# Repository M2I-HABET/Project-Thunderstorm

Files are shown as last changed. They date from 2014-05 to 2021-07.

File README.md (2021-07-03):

Project Thunderstorm
==================

Project Thunderstorm aims to launch high altitude balloons into thunderstorms in order to collect data. Multiple balloons will be launched to take data points at different points in the thunderstorm and to use a mesh network to help deliver information throughout the thunderstorm.

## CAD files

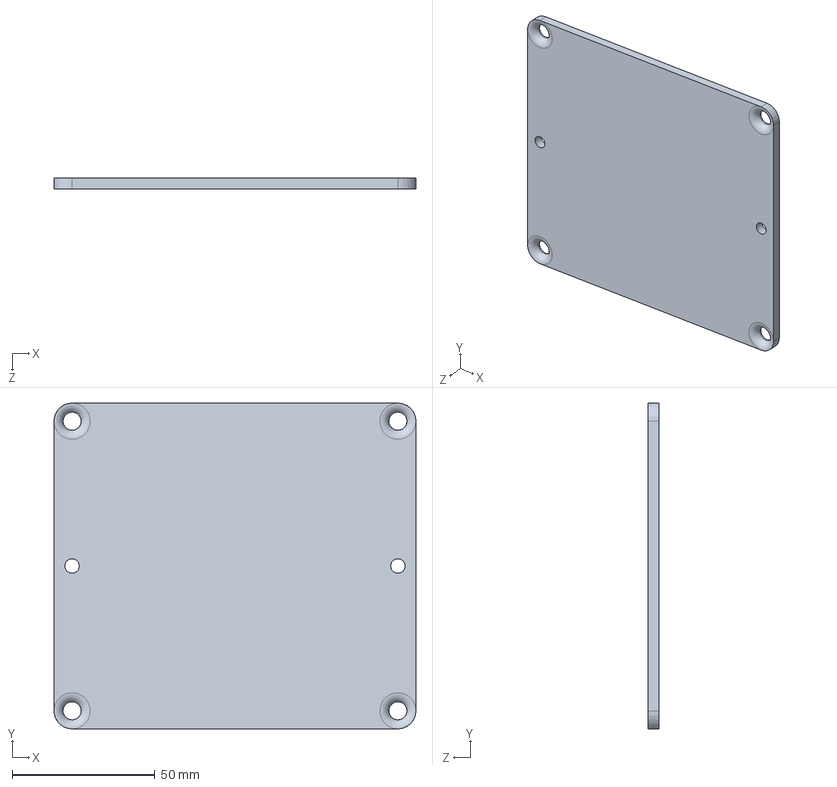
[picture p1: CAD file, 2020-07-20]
Enclosure/Lid 2.SLDPRT
127.0 x 114.3 x 3.81 mm

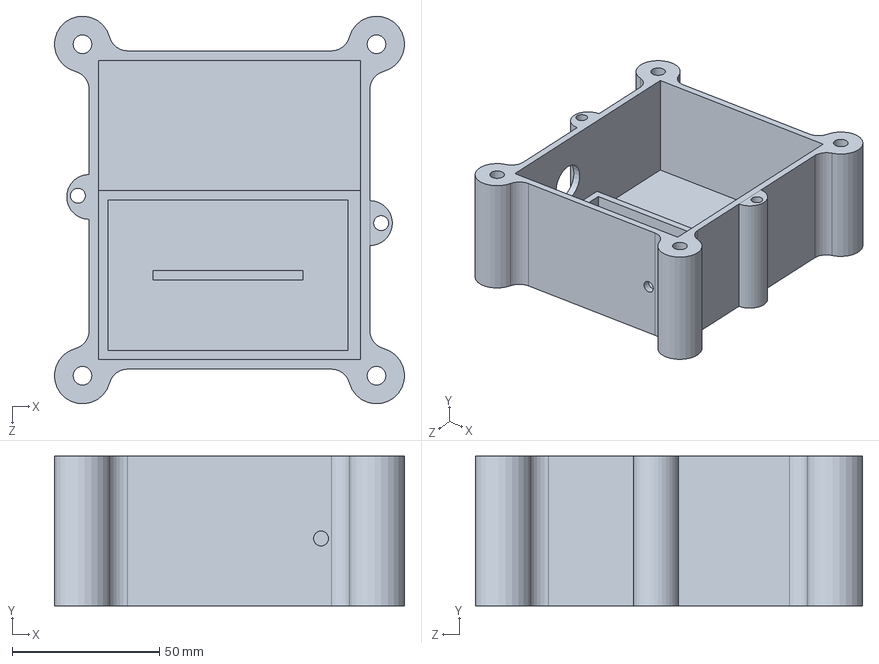
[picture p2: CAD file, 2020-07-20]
Enclosure/thunderstorm1.SLDPRT
118.7 x 50.8 x 131.4 mm

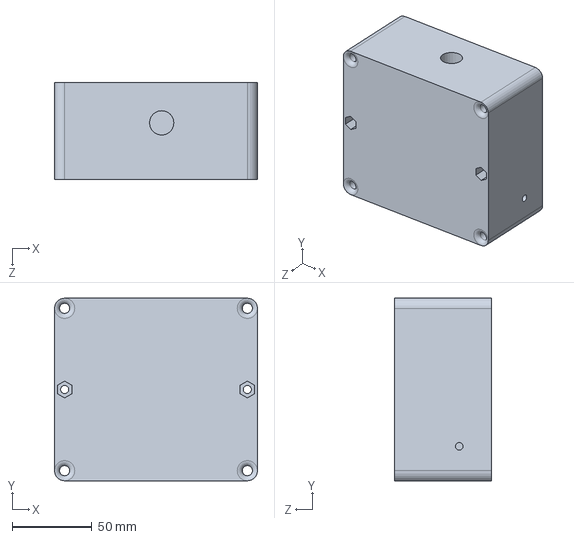
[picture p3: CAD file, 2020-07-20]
Enclosure/Box 2.SLDPRT
127.0 x 114.3 x 61.0 mm

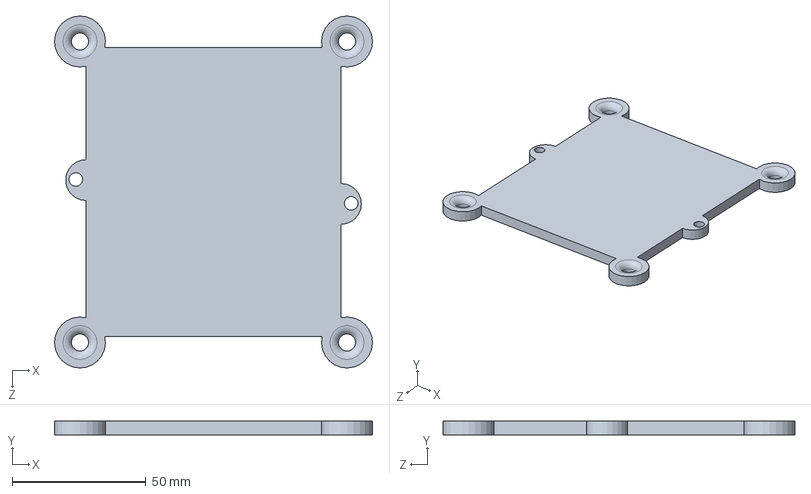
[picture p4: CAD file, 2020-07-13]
Enclosure/thunderstorm2.SLDPRT
118.8 x 5.08 x 131.5 mm

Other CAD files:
Enclosure/Box 2.STL
Enclosure/Lid 2.STL
Enclosure/thunderstorm1.STL
Enclosure/thunderstorm2.STL

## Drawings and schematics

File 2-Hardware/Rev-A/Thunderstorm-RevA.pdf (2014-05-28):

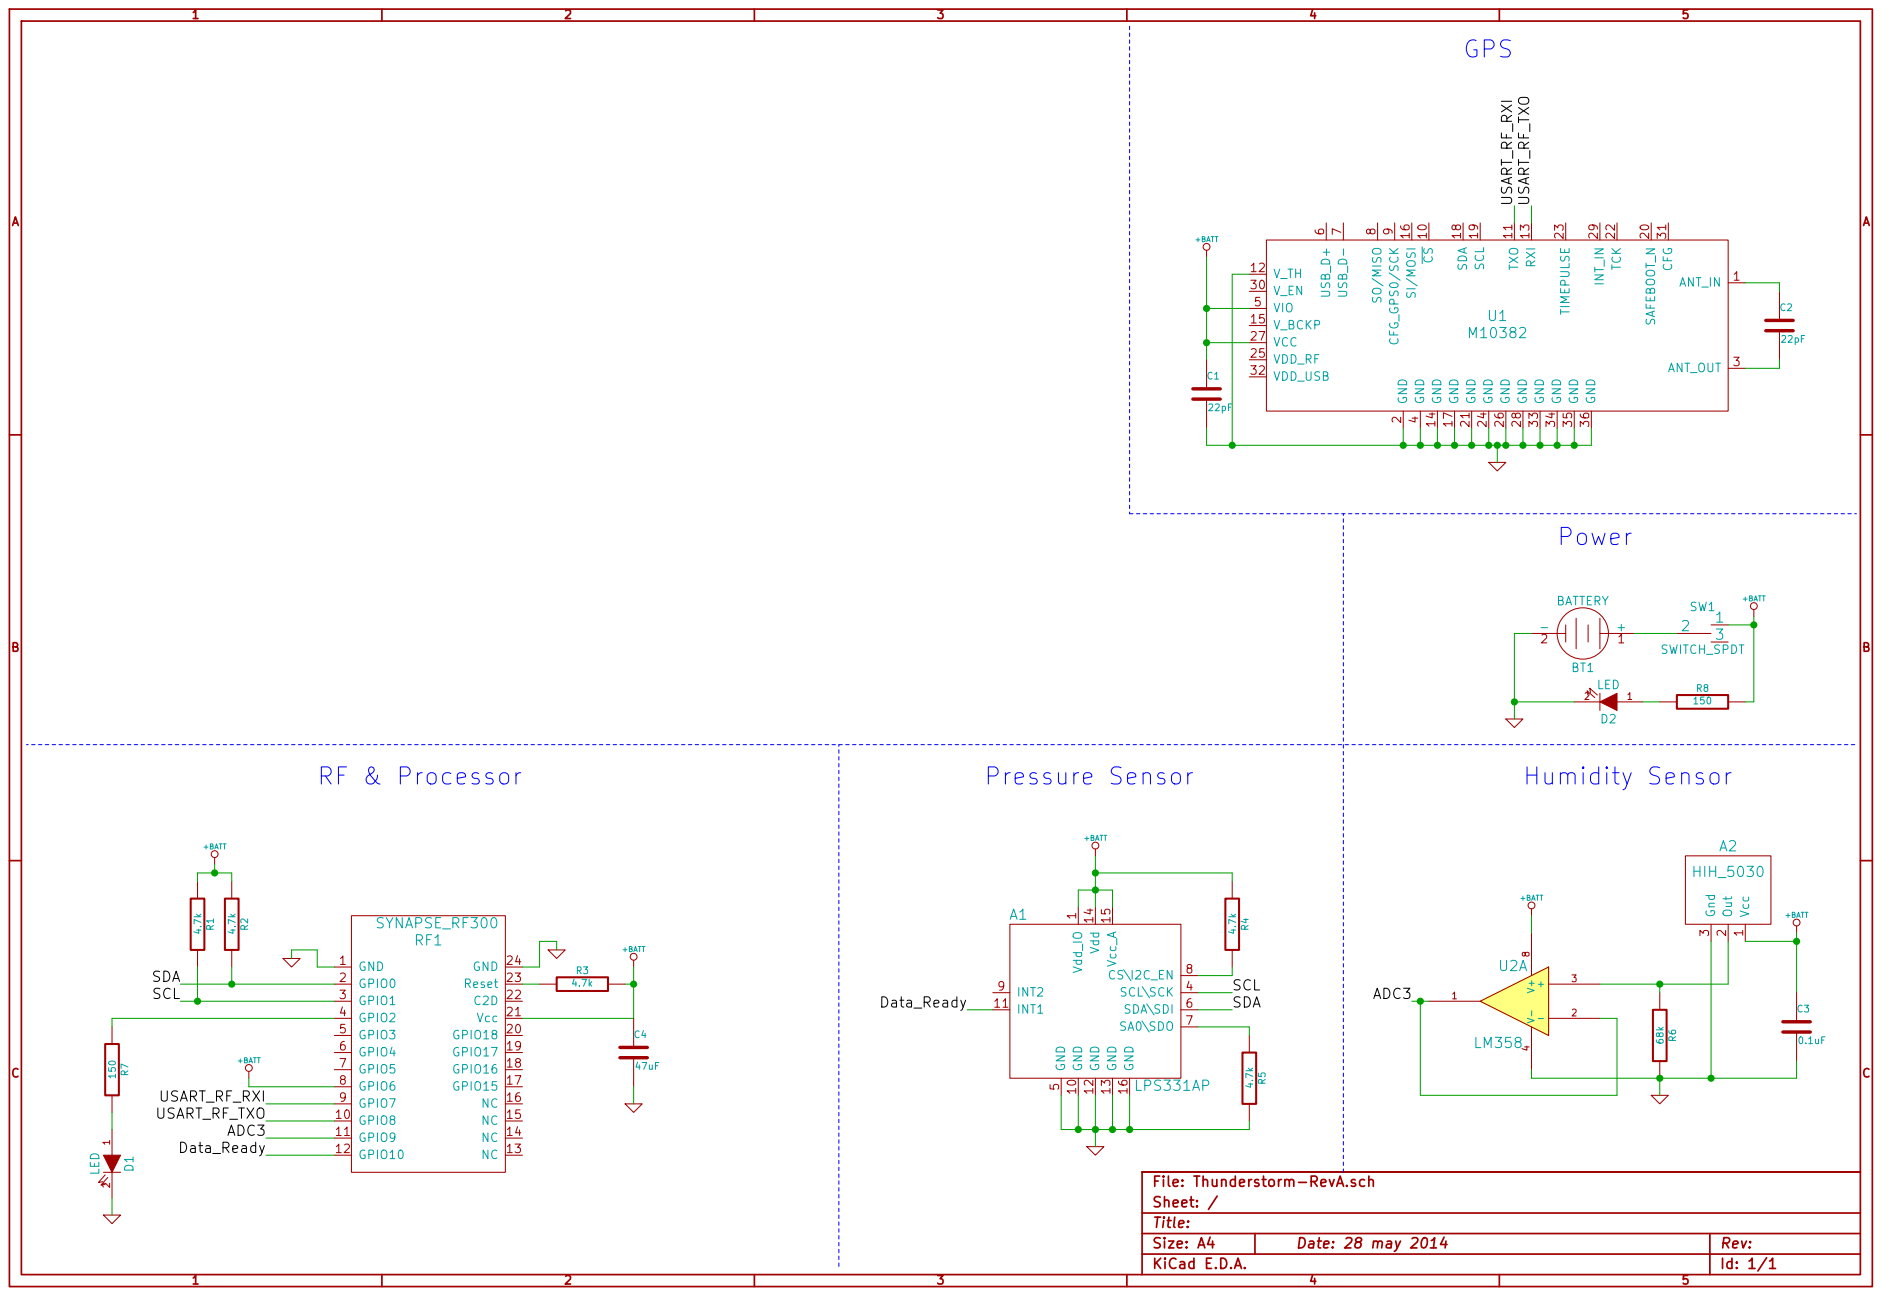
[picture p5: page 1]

9 CS 10 SAFEBOOT_N 20 V_EN 30 TXO 11 GND 21 CFG 31 V_TH 12 TCK 22 VDD_USB 32 RXI 13 TIMEPULSE 23 GND 33 GND 14 GND 24 GND 34 V_BCKP 15 VDD_RF 25 GND 35 SI/MOSI 16 GND 26 GND 36 GND 17 VCC 27 SDA 18 GND 28 SCL 19 INT_IN 29 U1 M10382
+BATT C1

5 SDA\SDI 6 SA0\SDO 7 CS\I2C_EN 8

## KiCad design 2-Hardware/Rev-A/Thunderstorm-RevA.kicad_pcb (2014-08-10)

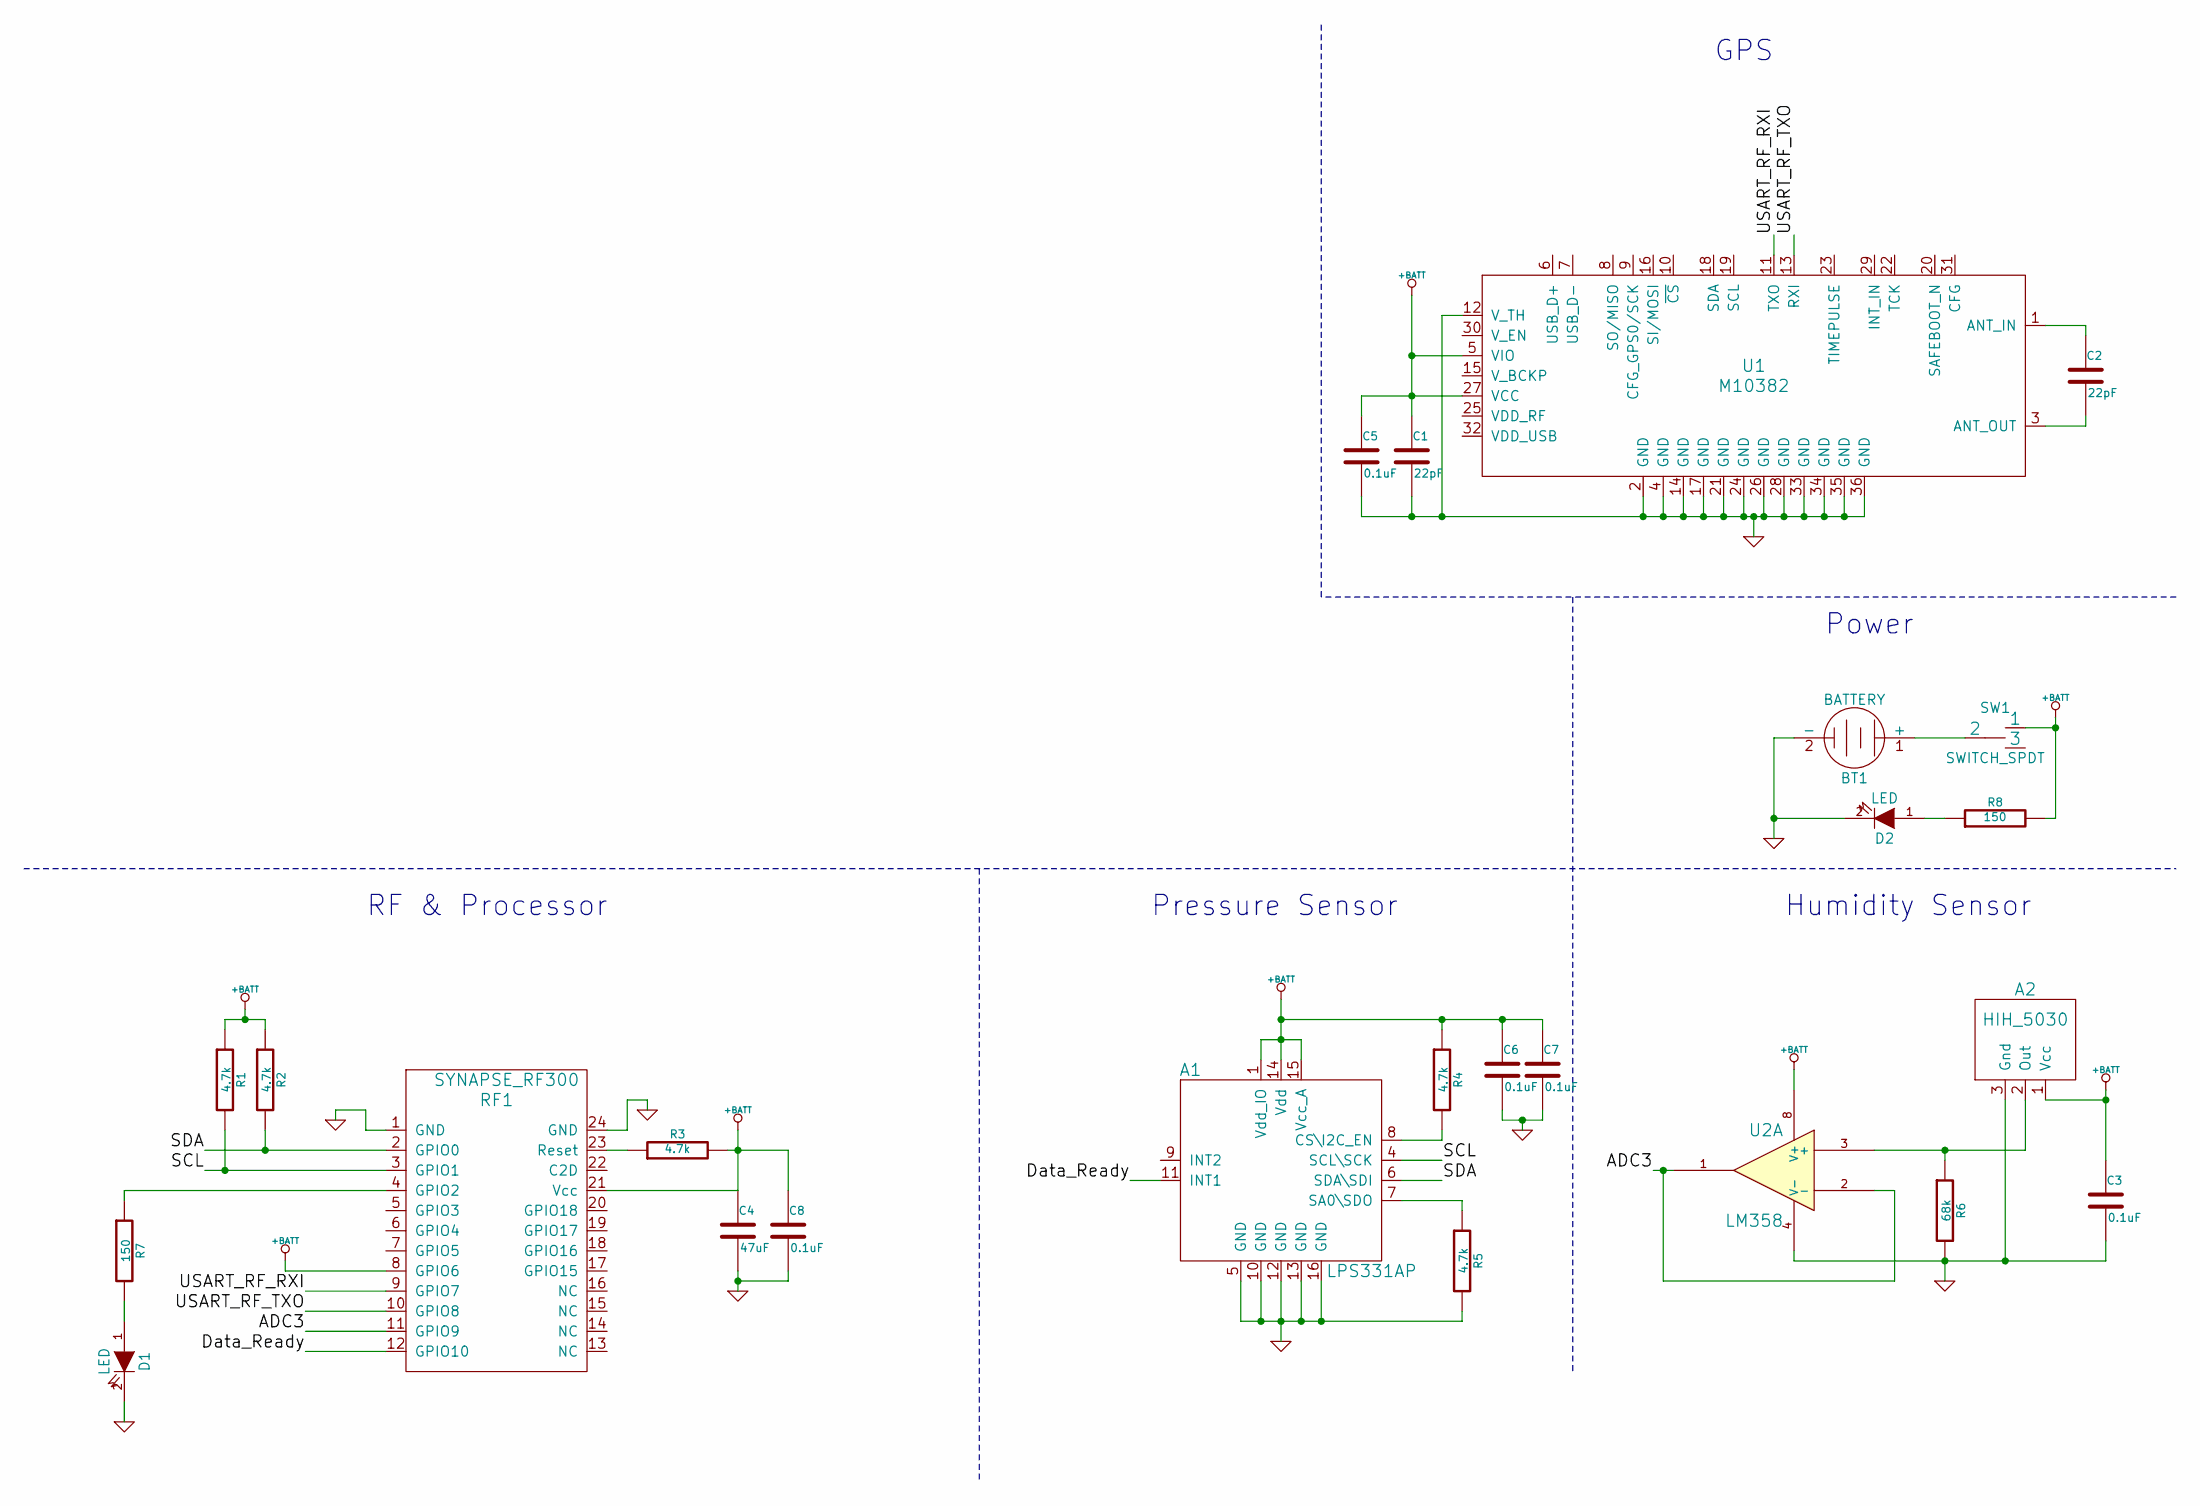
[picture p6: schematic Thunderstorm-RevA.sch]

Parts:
A1: LPS331AP
A2: HIH_5030
BT1: BATTERY
C1, C2: 22pF
C3, C5, C6, C7, C8: 0.1uF
C4: 47uF
D1, D2: LED
R1, R2, R3, R4, R5: 4.7k
R6: 68k
R7, R8: 150
RF1: SYNAPSE_RF300
SW1: SWITCH_SPDT
U1: M10382
U2: LM358

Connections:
+BATT: A1.1 (Vdd_IO), A1.14 (Vdd), A1.15 (Vcc_A), A2.1 (Vcc), C1.1, C3.1, C4.1, C5.1, C6.1, C7.1, C8.1, R1.1, R2.1, R3.2, R4.1, R8.2, RF1.8 (GPIO6), RF1.21 (Vcc), SW1.1, U1.5 (VIO), U1.27 (VCC), U2.8 (V+)
/ADC3: RF1.11 (GPIO9), U2.1, U2.2 (-)
/Data_Ready: A1.11 (INT1), RF1.12 (GPIO10)
/SCL: A1.4 (SCL\SCK), R1.2, RF1.3 (GPIO1)
/SDA: A1.6 (SDA\SDI), R2.2, RF1.2 (GPIO0)
/USART_RF_RXI: RF1.9 (GPIO7), U1.11 (TXO)
/USART_RF_TXO: RF1.10 (GPIO8), U1.13 (RXI)
GND: A1.5 (GND), A1.10 (GND), A1.12 (GND), A1.13 (GND), A1.16 (GND), A2.3 (Gnd), BT1.2 (-), C1.2, C3.2, C4.2, C5.2, C6.2, C7.2, C8.2, D1.2 (K), D2.2 (K), R5.2, R6.2, RF1.1 (GND), RF1.24 (GND), U1.2 (GND), U1.4 (GND), U1.12 (V_TH), U1.14 (GND), U1.17 (GND), U1.21 (GND), U1.24 (GND), U1.26 (GND), U1.28 (GND), U1.33 (GND), U1.34 (GND), U1.35 (GND), U1.36 (GND), U2.4 (V-)
unnamed: A1.7 (SA0\SDO), R5.1
unnamed: A1.8 (CS\I2C_EN), R4.2
unnamed: C2.2, U1.3 (ANT_OUT)
unnamed: C2.1, U1.1 (ANT_IN)
unnamed: A2.2 (Out), R6.1, U2.3 (+)
unnamed: R7.1, RF1.4 (GPIO2)
unnamed: D1.1 (A), R7.2
unnamed: D2.1 (A), R8.1
unnamed: R3.1, RF1.23 (Reset)
unnamed: BT1.1 (+), SW1.2

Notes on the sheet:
Humidity Sensor
GPS
RF & Processor
Power
Pressure Sensor

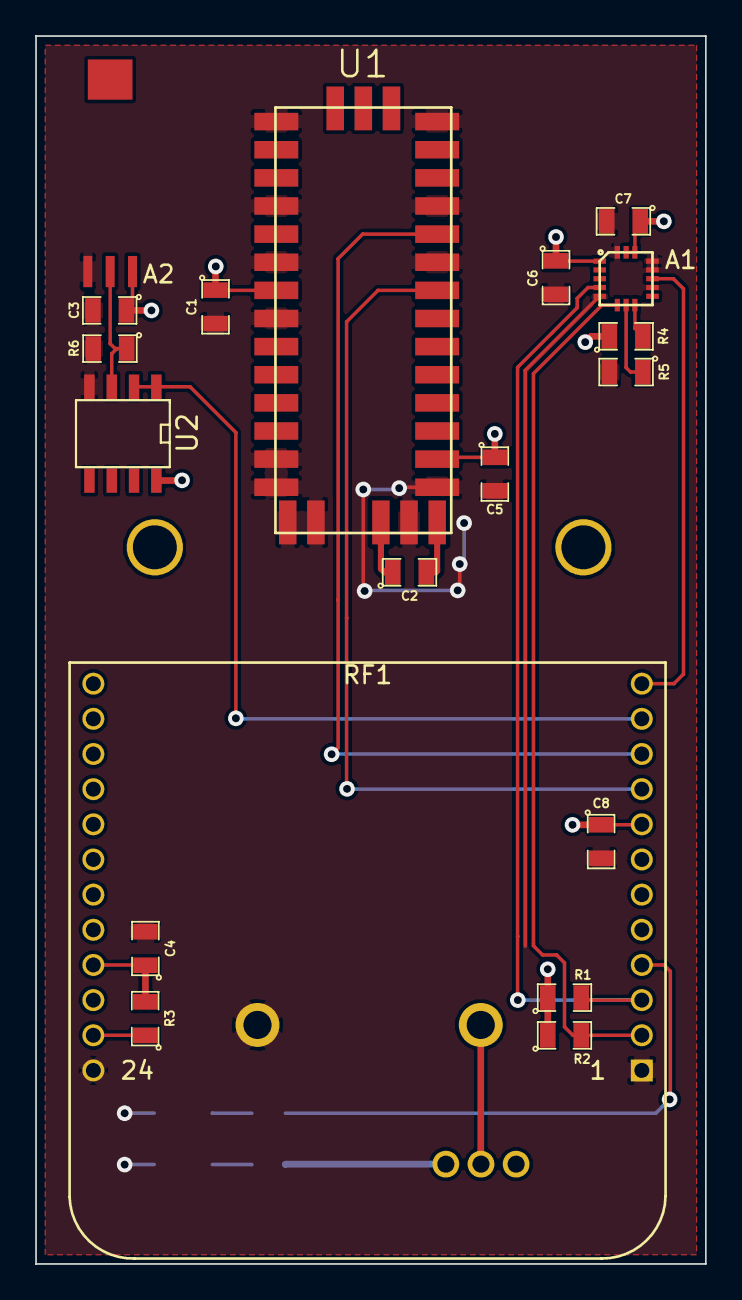
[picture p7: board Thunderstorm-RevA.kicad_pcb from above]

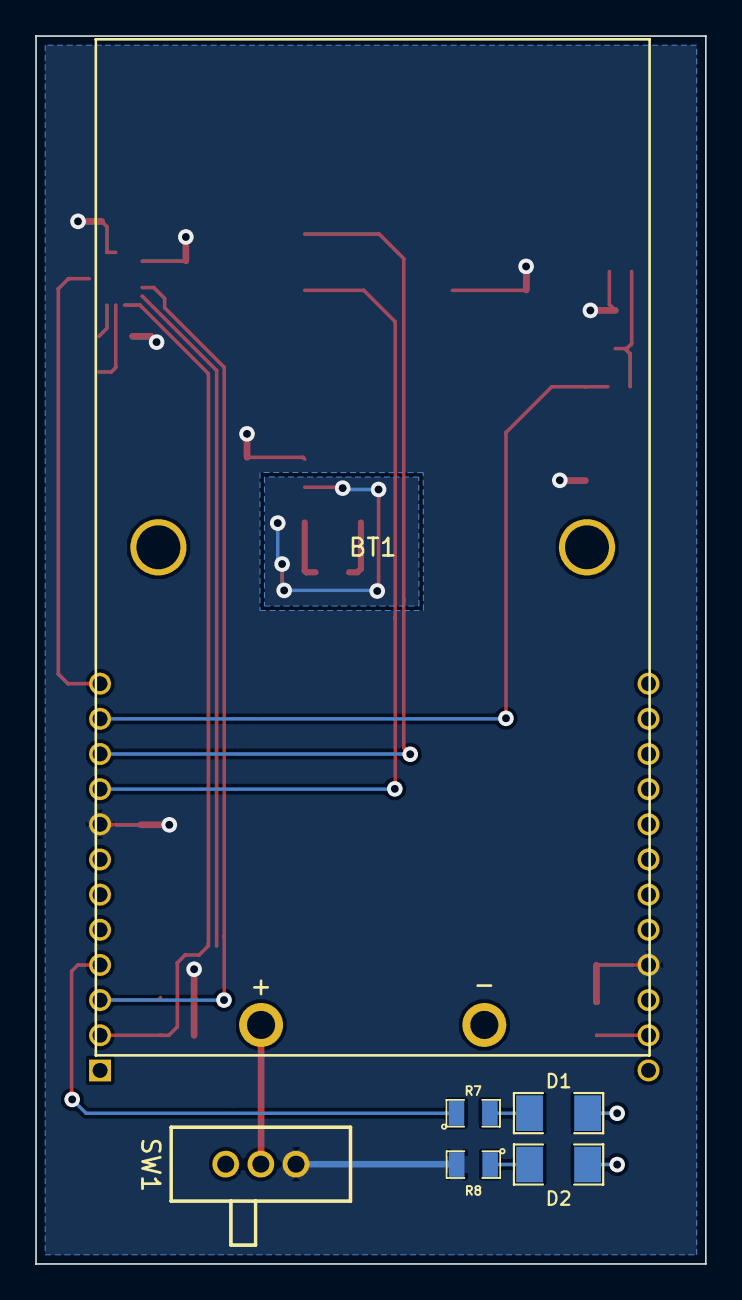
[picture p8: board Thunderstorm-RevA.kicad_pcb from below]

Board: 2 copper layers, 38.1 x 69.8 mm, 25 parts (6 on the bottom side), 18 nets.

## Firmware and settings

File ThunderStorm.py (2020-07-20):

# Write your code here :-)
# Simple GPS module demonstration.
# Will wait for a fix and print a message every second with the current location
# and other details.
import time
import board
import busio
import digitalio
import analogio

import adafruit_lsm9ds1
from busio import I2C
import adafruit_bme680
import adafruit_gps
import adafruit_rfm9x
import adafruit_max31865
 # Device ID
FEATHER_ID = b'4'

print("start up")

vbat_voltage = analogio.AnalogIn(board.VOLTAGE_MONITOR)

# Define pins connected to the chip, use these if wiring up the breakout according to the guide:
# pylint: disable=c-extension-no-member
CS = digitalio.DigitalInOut(board.D10)
HR = digitalio.DigitalInOut(board.A0)

# pylint: disable=c-extension-no-member
RESET = digitalio.DigitalInOut(board.D11)

# Define the onboard LED
LED = digitalio.DigitalInOut(board.D13)
LED.direction = digitalio.Direction.OUTPUT

# Initialize SPI bus.
spi = busio.SPI(board.SCK, MOSI=board.MOSI, MISO=board.MISO)


# Define radio frequency, MUST match gateway frequency.
RADIO_FREQ_MHZ = 433.0

# Initialze RFM radio
rfm9x = adafruit_rfm9x.RFM9x(spi, CS, RESET, RADIO_FREQ_MHZ)

# Set transmit power to max
rfm9x.tx_power = 23

# Define RX and TX pins for the board's serial port connected to the GPS.
# These are the defaults you should use for the GPS FeatherWing.
# For other boards set RX = GPS module TX, and TX = GPS module RX pins.
RX = board.RX
TX = board.TX

# Create a serial connection for the GPS connection using default speed and
# a slightly higher timeout (GPS modules typically update once a second).
uart = busio.UART(TX, RX, baudrate=9600, timeout=1)
#uartPayload = busio.UART(board.A1, RX, baudrate=9600, timeout=30)
# for a computer, use the pyserial library for uart access
#import serial
#uart = serial.Serial("/dev/ttyUSB0", baudrate=9600, timeout=3000)

# Create a GPS module instance.
#gps = adafruit_gps.GPS(uart, debug=False)

# Initialize the GPS module by changing what data it sends and at what rate.
# These are NMEA extensions for PMTK_314_SET_NMEA_OUTPUT and
# PMTK_220_SET_NMEA_UPDATERATE but you can send anything from here to adjust
# the GPS module behavior:
#   https://cdn-shop.adafruit.com/datasheets/PMTK_A11.pdf

# Turn on the basic GGA and RMC info (what you typically want)
#gps.send_command(b'PMTK314,1,1,0,1,0,0,0,0,0,0,0,0,0,0,0,0,0,0,0')
# Turn on just minimum info (RMC only, location):
#gps.send_command(b'PMTK314,0,1,0,0,0,0,0,0,0,0,0,0,0,0,0,0,0,0,0')
# Turn off everything:
#gps.send_command(b'PMTK314,0,0,0,0,0,0,0,0,0,0,0,0,0,0,0,0,0,0,0')
# Tuen on everything (not all of it is parsed!)
#gps.send_command(b'PMTK314,1,1,1,1,1,1,0,0,0,0,0,0,0,0,0,0,0,0,0')

# Set update rate to once a second (1hz) which is what you typically want.
#gps.send_command(b'PMTK220,1000')
# Or decrease to once every two seconds by doubling the millisecond value.
# Be sure to also increase your UART timeout above!
#gps.send_command(b'PMTK220,2000')
# You can also speed up the rate, but don't go too fast or else you can lose
# data during parsing.  This would be twice a second (2hz, 500ms delay):
#gps.send_command(b'PMTK220,500')

# Main loop runs forever printing the location, etc. every second.
last_print = time.monotonic()


# I2C connection:
i2c = busio.I2C(board.SCL, board.SDA)
#sensor = adafruit_lsm9ds1.LSM9DS1_I2C(i2c)

# Create library object using our Bus I2C port
#i2c = I2C(board.SCL, board.SDA)
bme680 = adafruit_bme680.Adafruit_BME680_I2C(i2c, debug=False)

# change this to match the location's pressure (hPa) at sea level
bme680.sea_level_pressure = 980

#SPI connection:
# from digitalio import DigitalInOut, Direction
# spi = busio.SPI(board.SCK, board.MOSI, board.MISO)
# csag = DigitalInOut(board.D5)
# csag.direction = Direction.OUTPUT
# csag.value = True
# csm = DigitalInOut(board.D6)
# csm.direction = Direction.OUTPUT
# csm.value = True
# sensor = adafruit_lsm9ds1.LSM9DS1_SPI(spi, csag, csm)

# Main loop will read the acceleration, magnetometer, gyroscope, Temperature
# values every second and print them out.


pt100 = adafruit_max31865.MAX31865(spi, HR, rtd_nominal=100, ref_resistor=430.0, wires=3)


def sendMessage(message):
    try:
        LED.value = True
        rfm9x.send(FEATHER_ID+b','+message)
        #print(FEATHER_ID+b','+message)
        time.sleep(.5)
        LED.value = False
    except:
        print("Message failed to send")

def getDat():
    temp = pt100.temperature
    RTemp = str('{0:0.3f}'.format(temp))
    B = 'ResTemp,'+ RTemp
    t = str(bme680.temperature)
    g = str(bme680.gas)
    h = str(bme680.humidity)
    p = str(bme680.pressure)
    a = str(bme680.altitude)
    battery_voltage = get_voltage(vbat_voltage)
    #print("VBat voltage: {:.2f}".format(battery_voltage))
    v = "{:.2f}".format(battery_voltage)

    A = t + ',' + g + ',' + h + ',' + p + ',' + a

    datstr = "DATA,BME," + A + "," + B + ",vbat," + v + ",eol"
    return(datstr)

def get_voltage(pin):
    return (pin.value * 3.3) / 65536 * 2

current = time.monotonic()
old = current
newGPS = False
while True:
    # Make sure to call gps.update() every loop iteration and at least twice
    # as fast as data comes from the GPS unit (usually every second).
    # This returns a bool that's true if it parsed new data (you can ignore it
    # though if you don't care and instead look at the has_fix property).
    #gps.update()
    # Every second print out current location details if there's a fix.

    #print("\nTemperature: %0.1f C" % bme680.temperature)
    #print("Gas: %d ohm" % bme680.gas)
    #print("Humidity: %0.1f %%" % bme680.humidity)
    #print("Pressure: %0.3f hPa" % bme680.pressure)
    #print("Altitude = %0.2f meters" % bme680.altitude)

    #t = bme680.temperature
    #g = bme680.gas

    #sensorString = "str(t),str(g)"
    #print(sensorString)

    #time.sleep(1)
    #time.sleep(1)

    #A = [t, g, h, p, a]
    #print(A)

    current = time.monotonic()
    #if current - last_print >= 1.0:
    if uart.in_waiting > 0:
        gps_string = uart.readline()
        print(gps_string)
        if "GPGGA" in gps_string:
            #old = current
            gps_str = str(gps_string)
            #print(gps_str)
            #sendMessage(gps_str + ",HABET")
            #datastr = getDat()
            #sendMessage(datastr)
            #print(datastr)
            newGPS = True
    if current-old>5:
        old = current
        if newGPS:
            print(gps_str)
            sendMessage(gps_str)
            datastr = getDat()
            sendMessage(datastr)
            print(datastr)
            newGPS = False
        else:
            sendMessage("No GPS")
            print("No GPS")
            datastr = getDat()
            sendMessage(datastr)
            print(datastr)
    packet = rfm9x.receive(timeout=.1)
    if packet is None:
        # Packet has not been received
        LED.value = False
        #print('Received nothing! Listening again...')
    else:
        # Received a packet!
        LED.value = True
        # Print out the raw bytes of the packet:
        #print('Received (raw bytes): {0}'.format(packet))
        # And decode to ASCII text and print it too.  Note that you always
        # receive raw bytes and need to convert to a text format like ASCII
        # if you intend to do string processing on your data.  Make sure the
        # sending side is sending ASCII data before you try to decode!
        try:
            rssi = rfm9x.rssi
            #print(packet)
            if(b'command' in packet):
                sendMessage(str(packet))
                print(str(packet))
        except:
            print("invalid ascii")
        # Also read the RSSI (signal strength) of the last received message and
        # print it.

    time.sleep(.05)

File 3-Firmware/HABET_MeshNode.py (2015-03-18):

##############################################################################
#
# HABET_MeshNode.py
#
# This script is designed to be run on a RF300 module to provide periodic
# link quality information with the node's current position.
#
# Author: Ian McInerney
##############################################################################


##############################################################################
# Various global variable initialization stuff
##############################################################################

# Define the multicast group that the node belongs to
MULTICAST_GROUP = 0x0002

# Store if there is currently a GPS string being buffered
# 0 = No string
# 1 = Incomplete string
# 2 = Complete string
gpsStringBuffered = 0

# The buffer for the GPS
gpsStringBuffered = {}

# The GPS decoded variables
gps_Latitude = -1
gps_Longitude = -1
gps_Altitude = -1
gps_Time = -1
gps_Satellites = -1


##########################################################################
# Run this code at startup
##########################################################################

@setHook(HOOK_STARTUP)
def _startupEvent():
    # Configure the multicast groups
    saveNvParam(5, MULTICAST_GROUP)
    saveNvParam(6, MULTICAST_GROUP)

    #configure the serial port for the GPS to go to the script
    initUart(0, 9600)
    crossConnect(1, 4) # Connect UART0 to STDIO
    

########################################################################
# This function is called whenever new data appears on the serial input
########################################################################

@setHook(HOOK_STDIN)
def _receiveSerialData(data):
    global gpsStringBuffered
    global gpsStringBuffer
    
    # Find the number of characters received
    receivedLength = len(data)
    
    if gpsStringBuffered == 0:
        # No string is buffered, search for the start character
        charLocation = _stringFindNextInstance(data, "$", 0)
        
        if( charLocation == -1):
            # No start character was found
            return
        
        # A start character exists, pull the string out
        gpsStringBuffer = data[charLocation+1:receivedLength]
        
        # We are now buffering a GPS string
        gpsStringBuffered = 1;
        
    elif gpsStringBuffered == 1:
        # A string is being bufferef, search for the stop character
        charLocation = _stringFindNextInstance(data, "*", 0)
        
        if( charLocation == -1):
            # No stop character was found, just add the entire string
            gpsStringBuffer = gpsStringBuffer + data
            
        else:
            # A stop character was found, only add the part before it
            gpsStringBuffer = gpsStringBuffer + data[:charLocation-1]
            gpsStringBuffered = 2
            
            _decodeGPS()            # Decode the GPS string
            gpsStringBuffered = 0   # There is no more string in the buffer
        



#################################################################
# These functions serve as the periodic data generation functions
#################################################################

# Call this function every second
@setHook(HOOK_1S)
def _secondTick():
    global tickCount
    tickCount = tickCount+1
    if tickCount == 10:
        # Every 10 seconds, send the link status
        _sendLinkStatus()
        tickCount = 0

# Send a link status update packet to each node in listening range (no hopping)
def _sendLinkStatus():
    global gps_Latitude
    global gps_Longitude
    global gps_Altitude
    global gps_Time
    global gps_Satellites

    #Send the most recent GPS location to each node in listening range
    mcastRpc(MULTICAST_GROUP, 1, 'receiveLinkStatus', gps_Time, gps_Latitude, gps_Longitude, gps_Altitude, gps_Satellites)
    

##########################################################################
# This function is called by remote nodes to do link information gathering
##########################################################################

# This function is called by remote nodes to update link status
def receiveLinkStatus(rec_gps_Time, rec_gps_Latitude, rec_gps_Longitude, rec_gps_Altitude, rec_gps_Satellites):
    receivedQuality = getLq()   # Read in the link quality right away
    sendingNode = rpcSourceAddr() # Get which node sent the RPC
    



#############################################################################
# The following functions are used to parse the GPS string from the Antennova
#############################################################################

# Break up a GPS string into its parts
def _decodeGPS(inputString):
    global gps_Latitude
    global gps_Longitude
    global gps_Altitude
    global gps_Time
    global gps_Satellites
    
    stringLength = len(inputString)
    
    # Return if it is not a GGA string
    if (inputString[:4] != "GPGGA"):
        return
    
    # Start after the "GPGGA," part
    i = 6;
    currentItem = 0;
    
    while( i < stringLength ):
        # Find the next comma after the current location
        nextComma = _stringFindNextInstance(inputString, ",", i)
        
        # Extract the substring from the string and store it appropriately
        if (currentItem == 0):
            # The GPS time string
            end = nextComma-1
            gps_Time = inputString[i+1:end]
            
        elif (currentItem == 1):
            # The GPS Latitude String
            # Note: This has two fields, the second is a single letter
            end = nextComma+1
            gps_Latitude = inputString[i+1:end]
            
        elif (currentItem == 2):
            # The GPS Longitude String
            # Note: This has two fields, the second is a single letter
            end = nextComma+1
            gps_Longitude = inputString[i+1:end]
            
        elif (currentItem == 4):
            # The GPS satellite count
            end = nextComma-1
            gps_Satellites = inputString[i+1:end]
            
        elif (currentItem == 6):
            # The GPS reported altitude
            # Note: This has two fields, the second is a single letter
            end = nextComma+1
            gps_Altitude = inputString[i+1:end]
        else:
            end = nextComma
            
        # Move onto the next field
        currentItem += 1
        
        # Set the index to be the start of the next field
        i = end+2
    


# Find the next instance of a character after a certain point
def _stringFindNextInstance(inputString, desiredChar, startIndex):
    inputLen = len(inputString)
    i = startIndex;
    
    # Iterate over the string's length
    while (i < inputLen):
        if (inputString[i] == desiredChar):
            # Record the location of the hit
            return(i)
        i += 1
    
    # If nothing is found, return -1
    return(-1)

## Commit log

2014-05-20 Completed revision A of the schematic.
    [Thunderstorm-RevA.sch]
2014-05-27 Changed humidity sensor part number to be correct (fixes #1). Updated op-amp circuit to fix incorrect negative terminal wiring (fixes #3). Changed ADC input for humidity sensor to connect Vref to Vcc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
    [Thunderstorm-RevA.sch]
2014-05-28 Fixed datasheet name for humidity sensor.
2014-05-28 Added LEDs for power and diagnostics. (Fixes #4).
    [Thunderstorm-RevA.sch]
2014-05-30 Added decoupling capacitors.
    [Thunderstorm-RevA.sch]
2014-05-30 Initial (unrouted) layout of PCB.
    [Thunderstorm-RevA.kicad_pcb]
2014-06-02 Added decoupling capacitor.
    [Thunderstorm-RevA.sch]
2014-06-02 Routed traces and created board outline.
    [Thunderstorm-RevA.kicad_pcb]
2014-06-02 Manufacturing outputs for running through FreeDFM.
    [Thunderstorm-RevA-B_Cu.gbl, Thunderstorm-RevA-B_Mask.gbs, Thunderstorm-RevA-Edge_Cuts.gbr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]
2014-08-10 Updated circuit board.
    [Thunderstorm-RevA.kicad_pcb]
2015-02-04 Created new gerber files, determined board size
    [Thunderstorm-RevA-B_Cu.gbl, Thunderstorm-RevA-B_Mask.gbs, Thunderstorm-RevA-Edge_Cuts.gbr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]
2020-05-07 Small code changes, fixed temp probe
    [ThunderStorm.py]
2020-07-10 Added enclosure solidworks files
    [thunderstorm1.SLDPRT, thunderstorm2.SLDPRT]
2020-07-10 THIS time it added the changed CircuitPython script
2020-07-13 Updated solidworks parts after first test print
    [thunderstorm1.SLDPRT, thunderstorm1.STL, thunderstorm2.SLDPRT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]
2020-07-20 Redid thunderstorm enclosures in solidworks. Also cleaned up ThunderStorm.py code and added battery voltage to data line
    [Box 2.SLDPRT, Box 2.STL, Lid 2.SLDPRT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]
